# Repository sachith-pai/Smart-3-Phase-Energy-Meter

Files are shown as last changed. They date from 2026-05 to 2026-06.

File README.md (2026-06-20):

# Smart-3-Phase-Enrgy-Meter
An ESPHome-based energy meter powered by PZEM-004T V4 and Seed Studio Xiao ESP32-C6/ESP32-C3
 <div align="center">
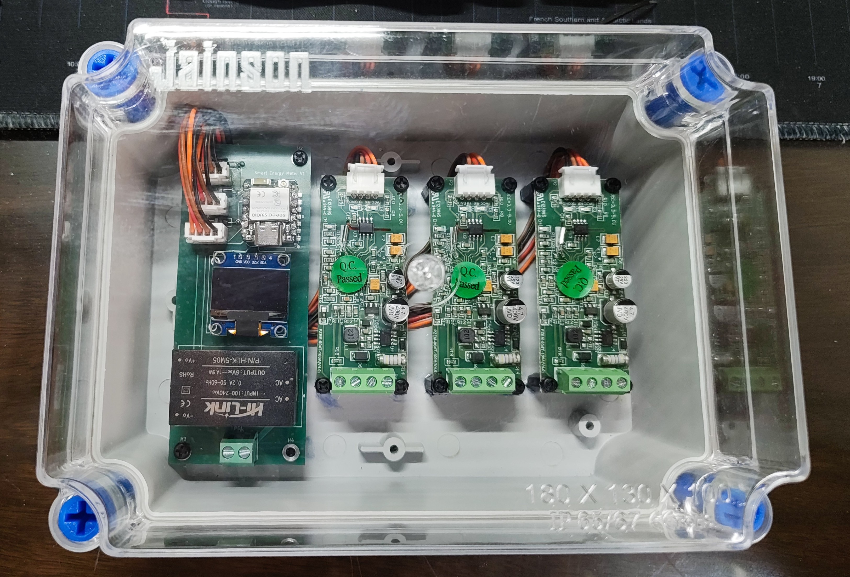
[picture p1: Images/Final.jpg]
  
</div>

## Componenets
1. [Seed Studio Xiao C6](https://www.seeedstudio.com/Seeed-Studio-XIAO-ESP32C6-p-5884.html) OR Xiao C3
2. [PZEM-004T V4](https://robu.in/product/pzem-004t-with-coil-ct-with-outcasehot-ac-meter/)
3. [SSD1306 0.96 OLED Display](https://quartzcomponents.com/products/oled-display-0-96-inch-i2c-interface-4-pin-blue-ssd1306)
4. [Hi-Link 5V 5W PSU (HLK 5M05)](https://robu.in/product/hlk-5m05-5v-5w-switch-power-supply-module/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)
5. [1N5819 Schottky barrier diode](https://robu.in/product/1n5819-1w-diode-pack-of-30/)
6. [4 Pin JST XH Male Connector - 2.54mm pitch](https://quartzcomponents.com/products/4-pin-jst-xh-male-connector-5-24mm-pitch)
7. [4 Pin JST Female to Female Connector - 2.54mm Pitch](https://quartzcomponents.com/products/4-pin-jst-female-to-female-connector-2-54mm-pitch)
8. [2 Pin Screw Terminal Block - 5mm Pitch](https://quartzcomponents.com/products/2-pin-pcb-mount-terminal-block-screw-type)
9. [Transparent Junction Box(180X130X100)](https://amzn.in/d/0d2WMVyG)

## Schematics 
 <div align="center">
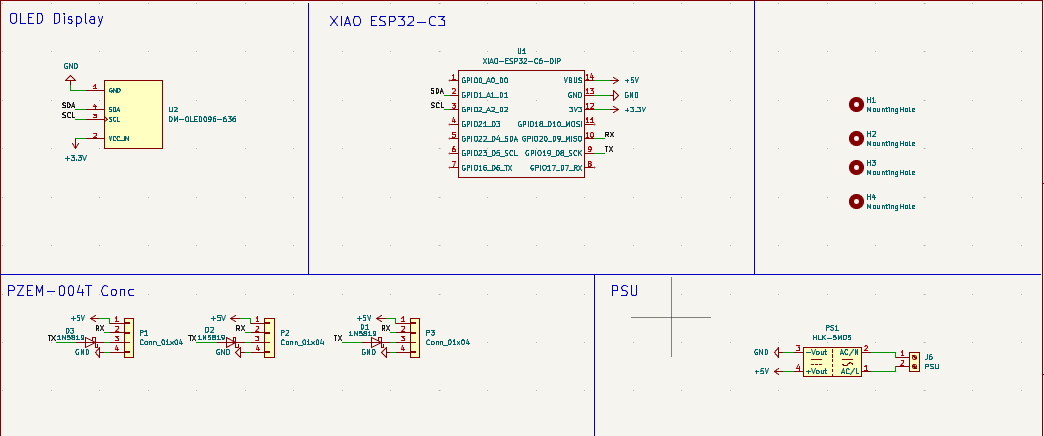
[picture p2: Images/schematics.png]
  
</div>

> [!NOTE]
>If ESPHome is unable to read from all three PZEM modules simultaneously, it is because multiple devices prevent the signal from dropping close enough to GND. To fix this, it is recommended to place a 1N5819  Schottky diode on the TX line of each PZEM .  Which I have included in the schematics as well as  in the PCB 

## PCB 

<table align="center">
  <tr>
    <td align="center">
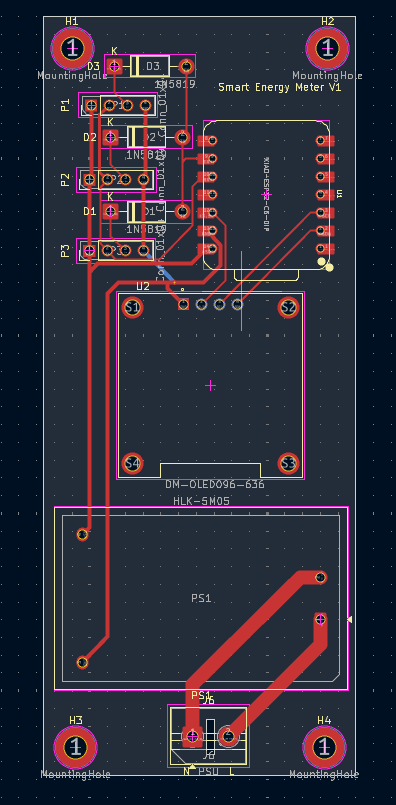
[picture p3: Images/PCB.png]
      <br>
    </td>
    <td align="center">
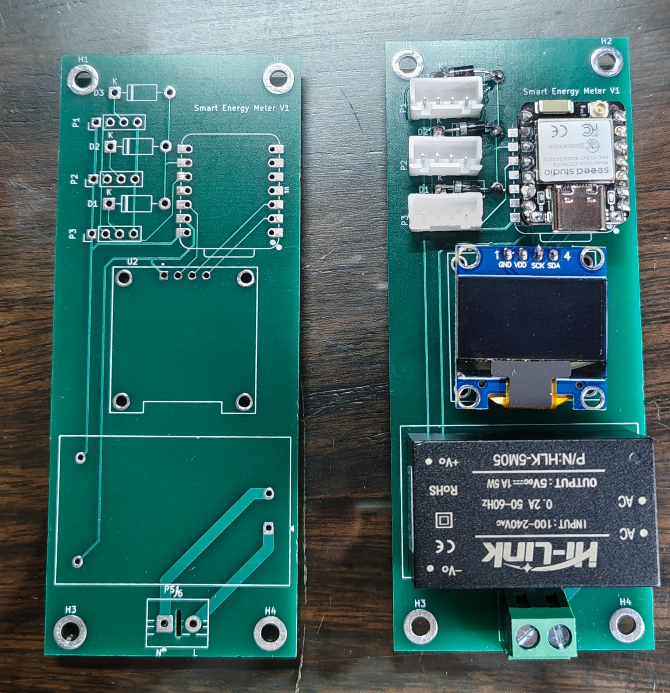
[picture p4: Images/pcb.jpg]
      <br>
    </td>

  </tr>
</table>

## Installtion 
1. Download the configuration of your board (c3 or c6), which can be found [HERE](/ESPHOME), and simply go to your ESPHome instance and "import from file" as shown in the picture 
  <div align="center">
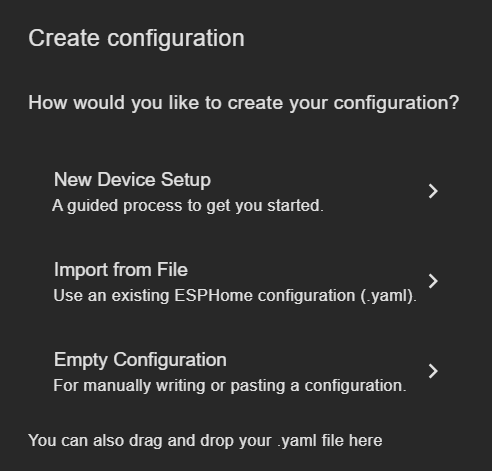
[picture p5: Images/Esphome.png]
  
</div>
2. Set the address to each of the Pzem-004T's using a USB to TTL Serial Adapter as follows

> [!NOTE]
> The address can also be changed in ESPHome, but this is recommended 

|Phase|Address|
|:--:|:--:|
|P1|0x01|
|P2|0x02|
|P3|0x03|

## Reference
1. [ESPHome Pzem-004T Docs](https://esphome.io/components/sensor/pzemac/)
2. [ESPHome SSD1306 OLED Display Docs](https://esphome.io/components/display/ssd1306/)
3. [Multiple Pzem Communication Error forum](https://community.home-assistant.io/t/pzem-004t-v4-0-esphome-not-able-to-read-simultaneously-from-all-3-pzems/957478/2)

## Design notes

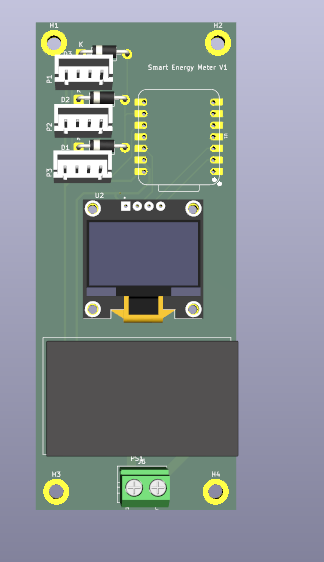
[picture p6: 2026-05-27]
Images/3D Model.png

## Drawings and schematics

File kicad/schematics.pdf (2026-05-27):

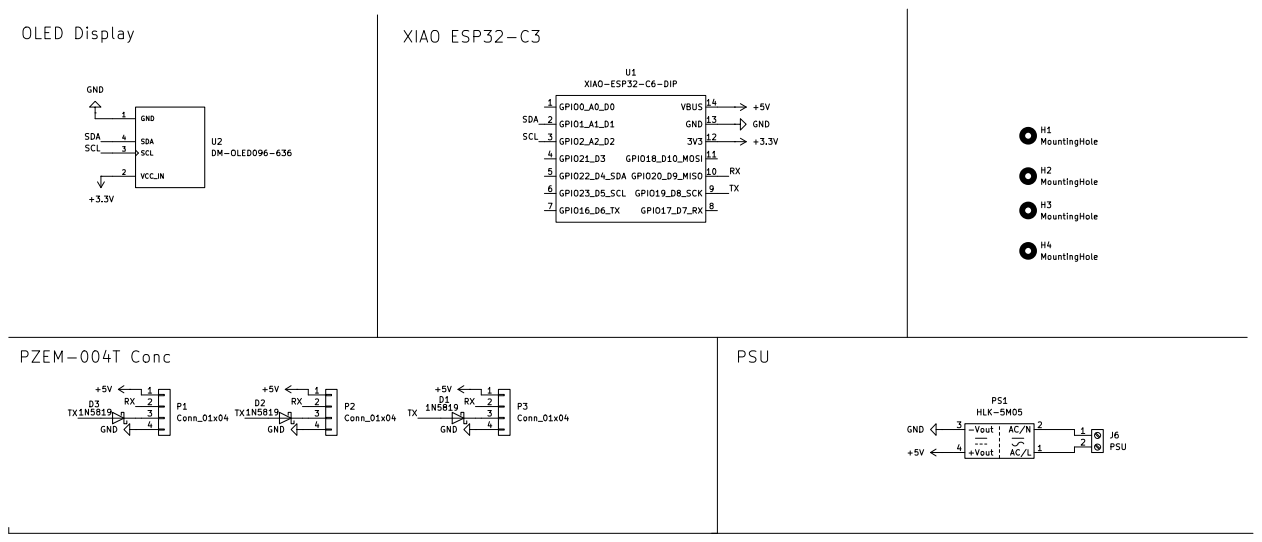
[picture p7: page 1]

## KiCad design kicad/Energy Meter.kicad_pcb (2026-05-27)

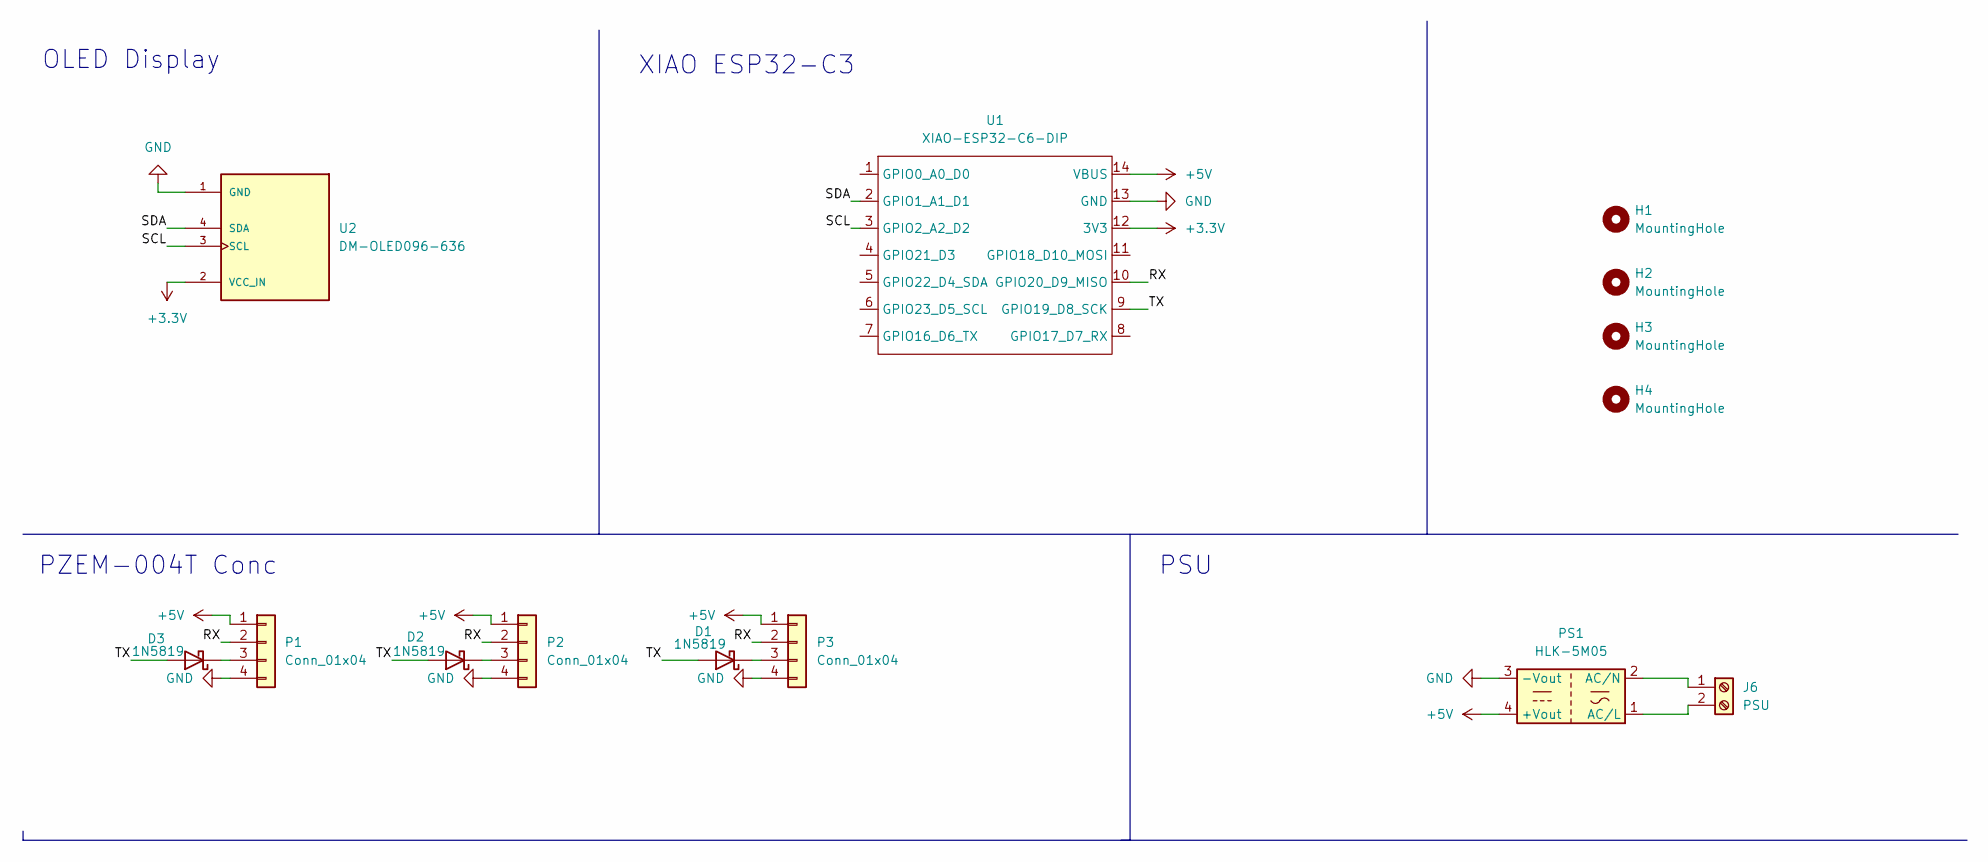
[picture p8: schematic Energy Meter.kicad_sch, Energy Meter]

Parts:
D1, D2, D3: 1N5819; D_DO-41_SOD81_P10.16mm_Horizontal
H1, H2, H3, H4: MountingHole; MountingHole_3.2mm_M3_ISO7380_Pad
J6: PSU; TerminalBlock_MaiXu_MX126-5.0-02P_1x02_P5.00mm
P1, P2, P3: Conn_01x04; PinHeader_1x04_P2.54mm_Vertical
PS1: HLK-5M05; Converter_ACDC_Hi-Link_HLK-5Mxx
U1: XIAO-ESP32-C6-DIP
U2: DM-OLED096-636; MODULE_DM-OLED096-636; PARTREV 2018-09-10

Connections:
+3.3V: U1.12 (3V3), U2.2 (VCC_IN)
+5V: P1.1, P2.1, P3.1, PS1.4 (+Vout), U1.14 (VBUS)
/RX: P1.2, P2.2, P3.2, U1.10 (GPIO20_D9_MISO)
/SCL: U1.3 (GPIO2_A2_D2), U2.3 (SCL)
/SDA: U1.2 (GPIO1_A1_D1), U2.4 (SDA)
/TX: D1.2 (A), D2.2 (A), D3.2 (A), U1.9 (GPIO19_D8_SCK)
GND: P1.4, P2.4, P3.4, PS1.3 (-Vout), U1.13 (GND), U2.1 (GND)
unnamed: D1.1 (K), P3.3
unnamed: D2.1 (K), P2.3
unnamed: D3.1 (K), P1.3
unnamed: J6.1, PS1.2 (AC/N)
unnamed: J6.2, PS1.1 (AC/L)

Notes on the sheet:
XIAO ESP32-C3
PSU
OLED Display
PZEM-004T Conc

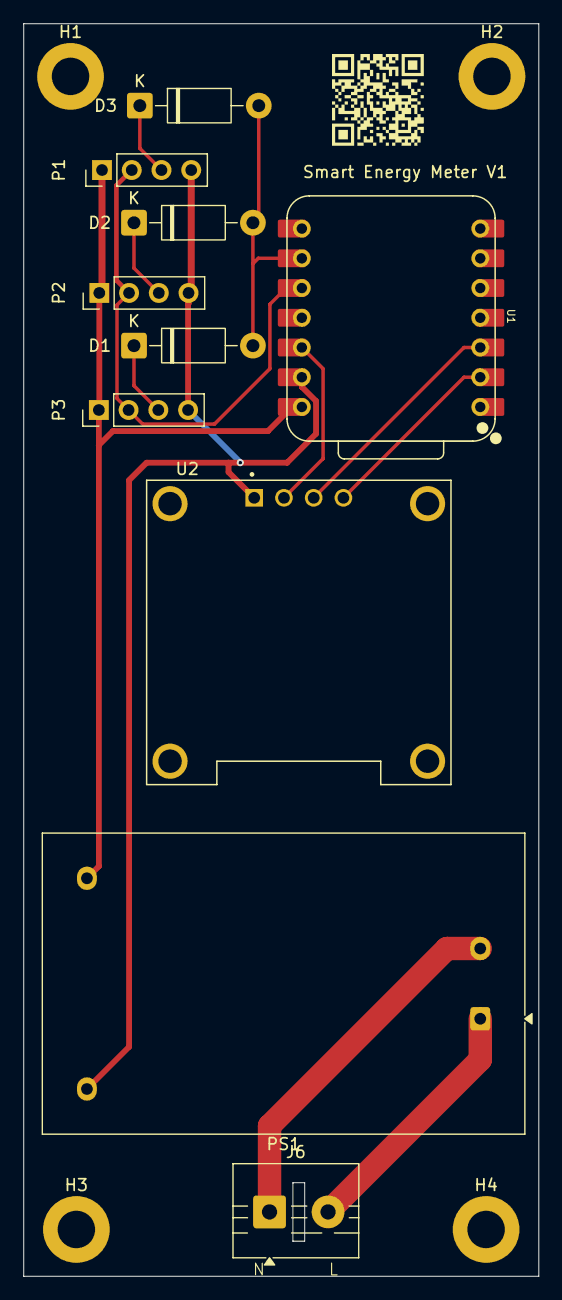
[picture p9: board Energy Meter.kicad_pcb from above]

Board: 2 copper layers, 44.0 x 107.0 mm, 14 parts (0 on the bottom side), 12 nets.
